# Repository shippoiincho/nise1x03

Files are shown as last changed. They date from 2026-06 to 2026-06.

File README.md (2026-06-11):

# 偽 1x03

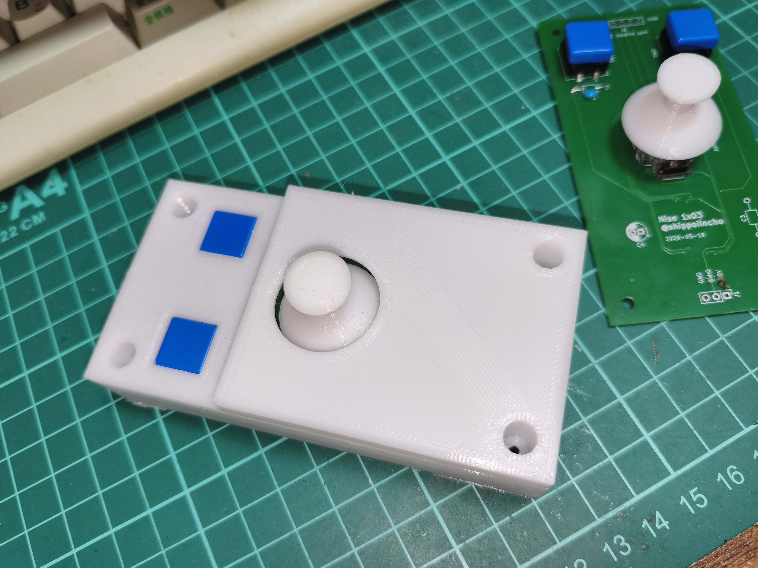
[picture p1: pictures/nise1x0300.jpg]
PCB


# これはなに

MZ-700/1500 用ジョイスティック MZ-1X03 のプロトコル互換のジョイスティックになります。
本体の専用コネクタに接続します。

# 回路とか

回路図は以下の通りになります。

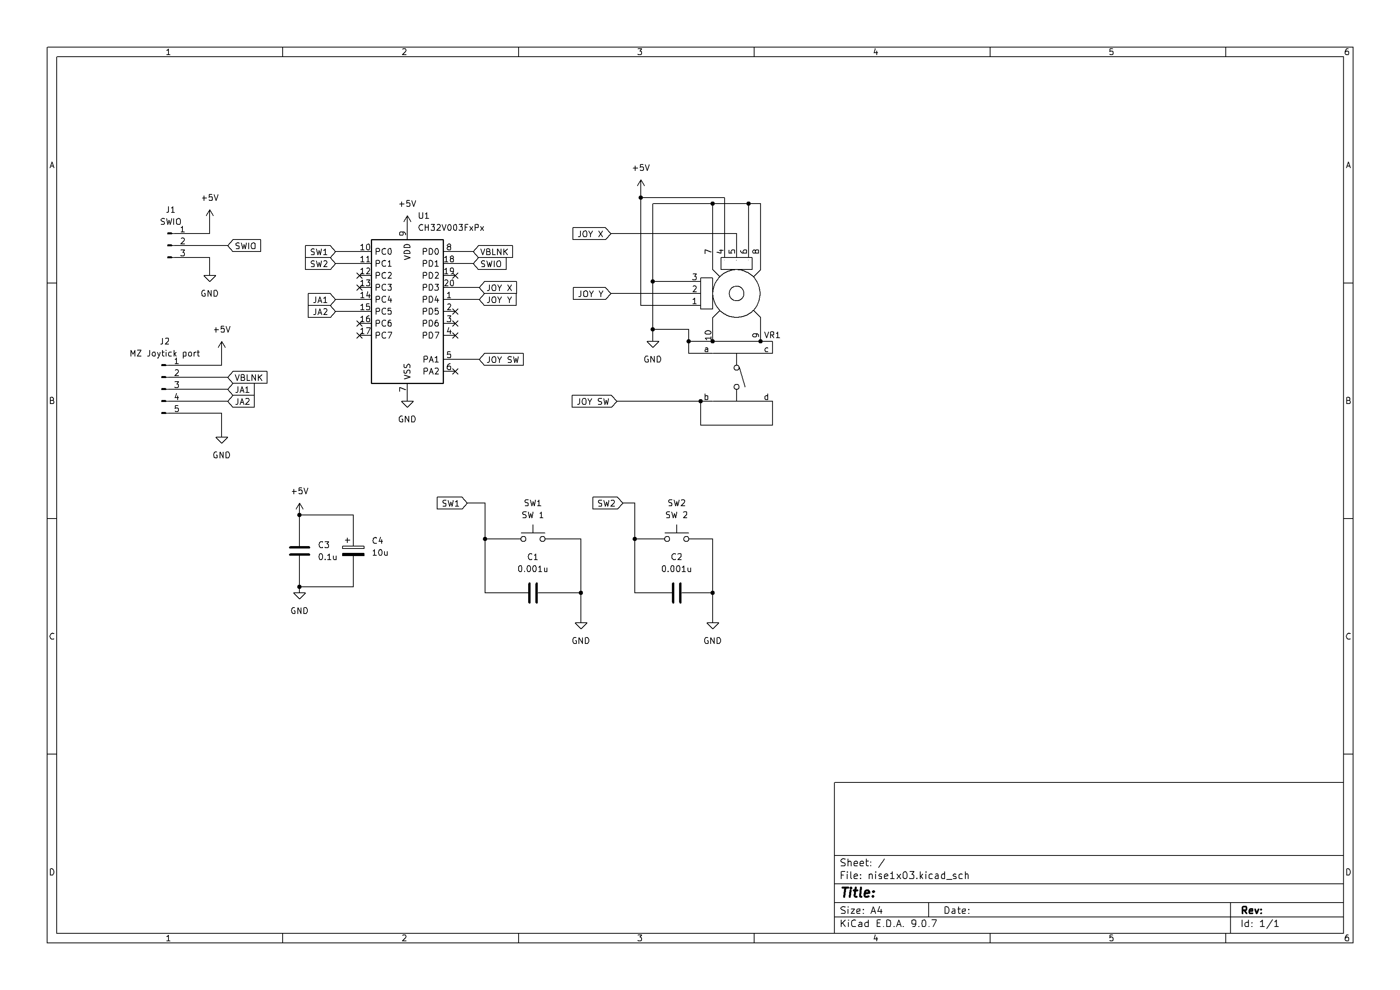
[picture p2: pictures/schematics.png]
schematics


HARDWARE の下にガーバデータと 3D プリンタ用筐体データがあります。

その他、必要なパーツは以下の通りです

- [CH32V003F4P6](https://akizukidenshi.com/catalog/g/g118061/)
- [ジョイスティックRKJXV122400R](https://akizukidenshi.com/catalog/g/g115951/)
- 12mm タクトスイッチ x2
- セラミックコンデンサ 1nF x 2
- セラミックコンデンサ 0.1uF x1
- 電解コンデンサ 10uF
- IL プラグ 5P
- IL コンタクト

本体のコネクタは向かって左が GND になっています。

# コードとか

MounRiverStudio (Ver.1) のプロジェクトになっています。
ビルドの上ファームウェアをダウンロードしてください。

書き込み用の端子は基板の下側にあります。

基板自体は CH32V00x シリーズで互換性がありますが、
ADC の仕様違いなどの関係で 003 以外で使用する場合には修正が必要です。

ジョイスティックの感度などは、以下のパラメータで調整できます。

```
#define SENSITIVE 13
#define TIMEFACTOR 850
```

BASIC の JOY 文などで、上(左)入力時に 0、下(右)入力時に 255 になるように調整してください。

# 制限事項

- 市販ソフトでの動作は未保障です
- ST-2 では感度２以上で動作することを確認をしています

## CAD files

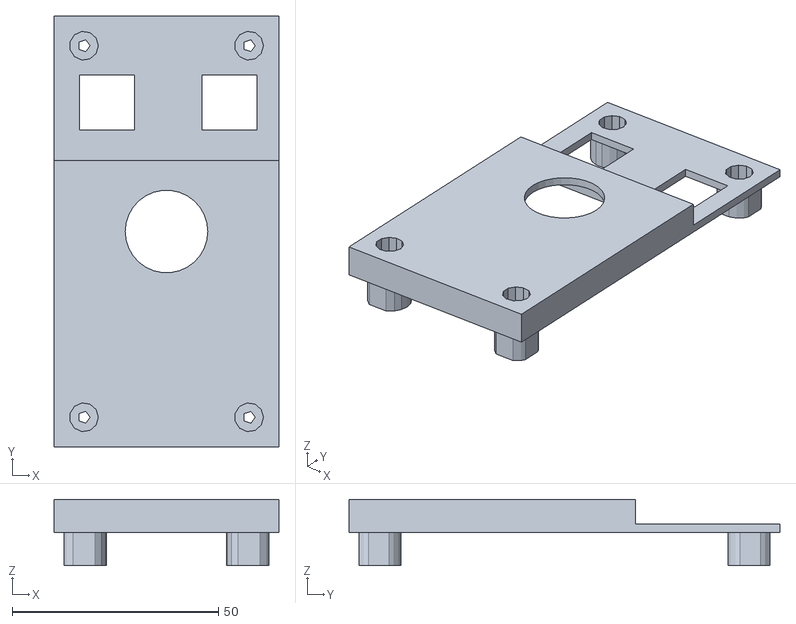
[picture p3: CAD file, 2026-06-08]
HARDWARE/MZ-1X03_top.stl
54.4 x 104.4 x 16.0

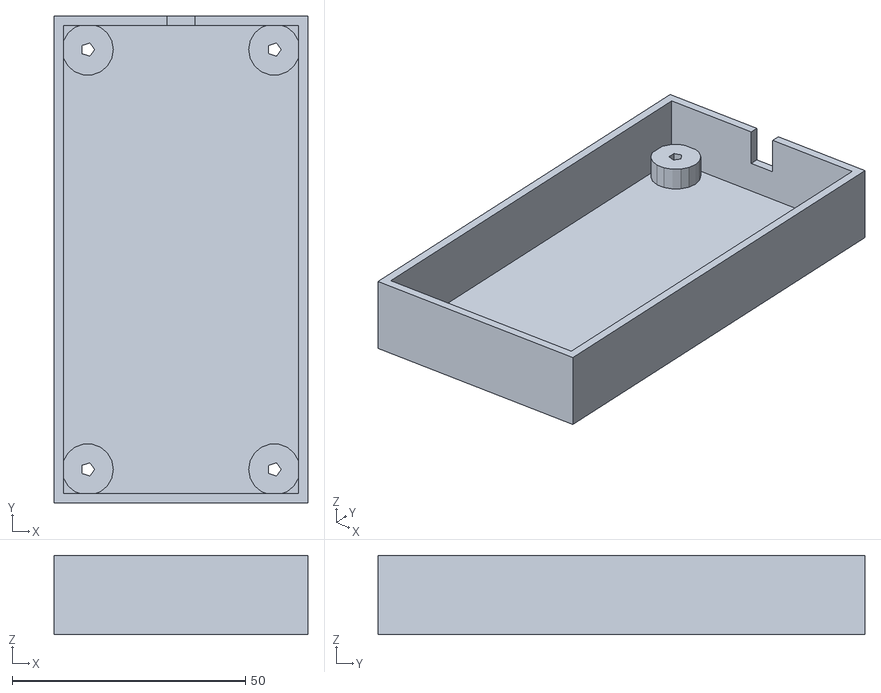
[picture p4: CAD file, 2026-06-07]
HARDWARE/MZ-1X03_bottom.stl
54.4 x 104.4 x 17.0

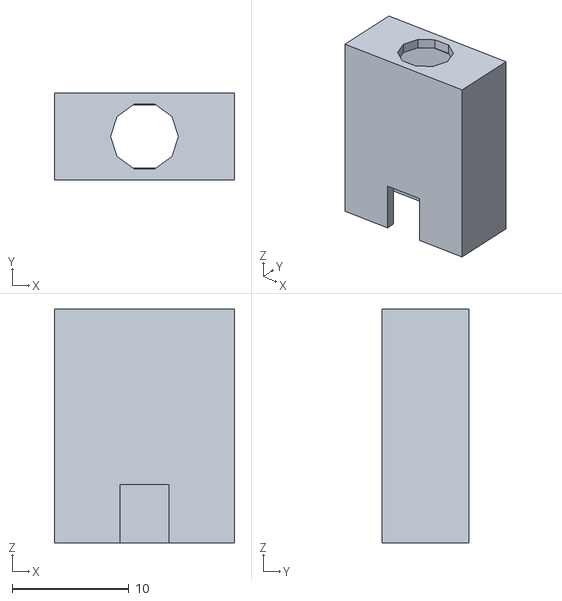
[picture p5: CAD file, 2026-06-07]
HARDWARE/MZ-1X03_conn.stl
15.4 x 7.40 x 20.0

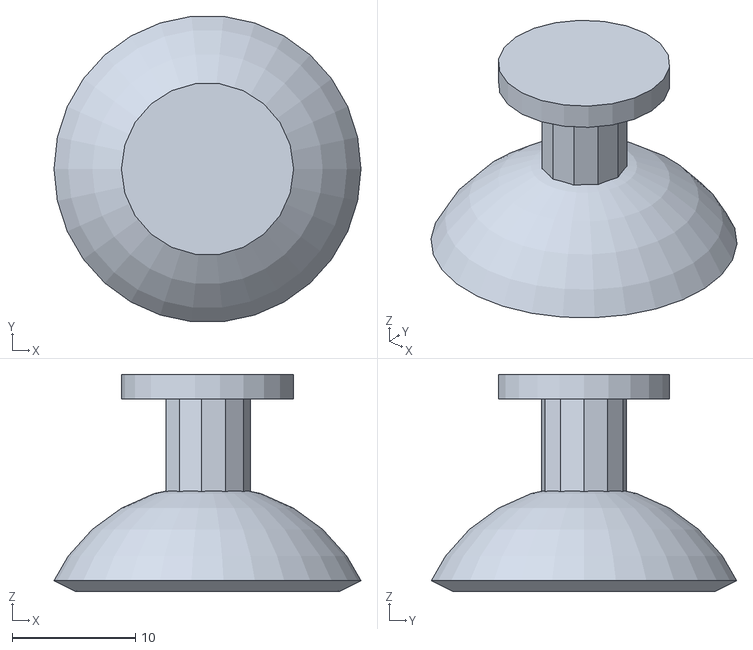
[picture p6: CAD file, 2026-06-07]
HARDWARE/MZ-1X03_cap.stl
25.0 x 24.8 x 17.7

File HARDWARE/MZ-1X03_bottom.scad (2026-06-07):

DEPTH=15;
SIZEX=25;
SIZEY=50;
HOLE=5;

MARGIN=0.2;
THICK=2.0;

DIFF=THICK/2;

// OUTER BOX

difference() {

translate([-SIZEX-MARGIN-THICK,-SIZEY-MARGIN-THICK,-DEPTH-THICK]) {    
cube([SIZEX*2+MARGIN*2+THICK*2,SIZEY*2+MARGIN*2+THICK*2,DEPTH+THICK]);
}

{
translate([-SIZEX-MARGIN,-SIZEY-MARGIN,-DEPTH]) {  
cube([SIZEX*2+MARGIN*2,SIZEY*2+MARGIN*2,DEPTH]);
}

// Mounting Hole

translate([-SIZEX+HOLE,-SIZEY+HOLE,-DEPTH-THICK]) {
cylinder(THICK,3.5,3.5);    
}

translate([-SIZEX+HOLE,SIZEY-HOLE,-DEPTH-THICK]) {
cylinder(THICK,3.5,3.5);    
}

translate([SIZEX-HOLE,-SIZEY+HOLE,-DEPTH-THICK]) {
cylinder(THICK,3.5,3.5);    
}

translate([SIZEX-HOLE,SIZEY-HOLE,-DEPTH-THICK]) {
cylinder(THICK,3.5,3.5);    
}

// Cable Guide

translate([-3,SIZEY,-8]) {
    cube([6,6,8]);
}

}

}

// Mounting Hole

difference() {
translate([-SIZEX+HOLE,-SIZEY+HOLE,-DEPTH]) {
cylinder(DEPTH-12,5.5,5.5);    
}
translate([-SIZEX+HOLE,-SIZEY+HOLE,-DEPTH]) {
cylinder(DEPTH-12,3.5,3.5);    
}
}

difference() {
translate([-SIZEX+HOLE,-SIZEY+HOLE,-12]) {
cylinder(2,5.5,5.5);    
}

translate([-SIZEX+HOLE,-SIZEY+HOLE,-12]) {
cylinder(2,1.5,1.5);    
}
}


difference() {
translate([-SIZEX+HOLE,SIZEY-HOLE,-DEPTH]) {
cylinder(DEPTH-12,5.5,5.5);    
}
translate([-SIZEX+HOLE,SIZEY-HOLE,-DEPTH]) {
cylinder(DEPTH-12,3.5,3.5);    
}
}

difference() {
translate([-SIZEX+HOLE,SIZEY-HOLE,-12]) {
cylinder(2,5.5,5.5);    
}

translate([-SIZEX+HOLE,SIZEY-HOLE,-12]) {
cylinder(2,1.5,1.5);    
}
}


difference() {
translate([SIZEX-HOLE,-SIZEY+HOLE,-DEPTH]) {
cylinder(DEPTH-12,5.5,5.5);    
}
translate([SIZEX-HOLE,-SIZEY+HOLE,-DEPTH]) {
cylinder(DEPTH-12,3.5,3.5);    
}
}

difference() {
translate([SIZEX-HOLE,-SIZEY+HOLE,-12]) {
cylinder(2,5.5,5.5);    
}

translate([SIZEX-HOLE,-SIZEY+HOLE,-12]) {
cylinder(2,1.5,1.5);    
}
}


difference() {
translate([SIZEX-HOLE,SIZEY-HOLE,-DEPTH]) {
cylinder(DEPTH-12,5.5,5.5);    
}
translate([SIZEX-HOLE,SIZEY-HOLE,-DEPTH]) {
cylinder(DEPTH-12,3.5,3.5);    
}
}

difference() {
translate([SIZEX-HOLE,SIZEY-HOLE,-12]) {
cylinder(2,5.5,5.5);    
}

translate([SIZEX-HOLE,SIZEY-HOLE,-12]) {
cylinder(2,1.5,1.5);    
}
}

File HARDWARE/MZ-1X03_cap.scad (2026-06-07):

MARGIN=0.2;

difference() {

intersection() {

difference() {
    
sphere(14);

sphere(12);

}

cylinder(15,0,30);

}

translate([-2-MARGIN,-1.5-MARGIN,10]) {
cube([4+MARGIN*2,3+MARGIN*2,4]);
}

}



difference() {

translate([0,0,11]) {
    cylinder(10,3.5,3.5);
}

translate([-2-MARGIN,-1.5-MARGIN,11]) {
cube([4+MARGIN*2,3+MARGIN*2,5]);
}


}

translate([0,0,21]) {
    cylinder(2,7,7);
}

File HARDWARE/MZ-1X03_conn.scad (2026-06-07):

difference() {

translate([-7.7,-3.7,0]) {    
cube([15.4,7.4,20]);
}

{
translate([-6.6,-2.7,0]) {  
cube([13.4,5.4,19]);
}

translate([-2.1,-3.7,-0]) {       
cube([4.2,2.2,5]);
    
}

translate([0,0,19]) {

cylinder(5,2.9,2.9);    
    
}

}

}

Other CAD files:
HARDWARE/MZ-1X03_top.scad

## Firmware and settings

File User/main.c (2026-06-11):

// Nise 1x03
// MZ-1X03 Emulator

// Pin connections
// PC0: SW1
// PC1: SW2
// PC4: JA1
// PC5: JA2
// PD0: VBLNK
// PD3: JOY X
// PD4: JOY Y

#include "debug.h"

#define SENSITIVE 13
#define TIMEFACTOR 850


// Initialize

void initgpio(void) {

    RCC_APB2PeriphClockCmd(RCC_APB2Periph_GPIOD | RCC_APB2Periph_GPIOC, ENABLE);


    GPIO_InitTypeDef  GPIO_InitStructure = {0};

    // PC0 & 1 for input with pull up

    GPIO_InitStructure.GPIO_Pin = GPIO_Pin_0 | GPIO_Pin_1;
    GPIO_InitStructure.GPIO_Speed = GPIO_Speed_50MHz;
    GPIO_InitStructure.GPIO_Mode = GPIO_Mode_IPU;
    GPIO_Init(GPIOC, &GPIO_InitStructure);

    // PC4 & 5 for output

    GPIO_InitStructure.GPIO_Pin = GPIO_Pin_4 | GPIO_Pin_5;
    GPIO_InitStructure.GPIO_Speed = GPIO_Speed_50MHz;
    GPIO_InitStructure.GPIO_Mode = GPIO_Mode_Out_PP;
    GPIO_Init(GPIOC, &GPIO_InitStructure);

    // PD0 for input

    GPIO_InitStructure.GPIO_Pin = GPIO_Pin_0 ;
    GPIO_InitStructure.GPIO_Speed = GPIO_Speed_50MHz;
    GPIO_InitStructure.GPIO_Mode = GPIO_Mode_IPU;
    GPIO_Init(GPIOD, &GPIO_InitStructure);

    // PD3 & 4 for ADC ch 4/5

    GPIO_InitStructure.GPIO_Pin = GPIO_Pin_3 | GPIO_Pin_4;
    GPIO_InitStructure.GPIO_Speed = GPIO_Speed_50MHz;
    GPIO_InitStructure.GPIO_Mode = GPIO_Mode_AIN;
    GPIO_Init(GPIOD, &GPIO_InitStructure);

}

void initadc(void) {

    ADC_InitTypeDef  ADC_InitStructure = {0};

    RCC_APB2PeriphClockCmd(RCC_APB2Periph_ADC1, ENABLE);
    RCC_ADCCLKConfig(RCC_PCLK2_Div8);

    ADC_DeInit(ADC1);
    ADC_InitStructure.ADC_Mode = ADC_Mode_Independent;
    ADC_InitStructure.ADC_ScanConvMode = DISABLE;
    ADC_InitStructure.ADC_ContinuousConvMode = DISABLE;
    ADC_InitStructure.ADC_ExternalTrigConv = ADC_ExternalTrigConv_None;
    ADC_InitStructure.ADC_DataAlign = ADC_DataAlign_Right;
    ADC_InitStructure.ADC_NbrOfChannel = 1;
    ADC_Init(ADC1, &ADC_InitStructure);

    ADC_Calibration_Vol(ADC1, ADC_CALVOL_50PERCENT);
    ADC_Cmd(ADC1, ENABLE);

    ADC_ResetCalibration(ADC1);
    while(ADC_GetResetCalibrationStatus(ADC1));
    ADC_StartCalibration(ADC1);
    while(ADC_GetCalibrationStatus(ADC1));


}

uint16_t getadc(uint8_t ch)
{
    uint16_t val;

    ADC_RegularChannelConfig(ADC1, ch, 1, ADC_SampleTime_241Cycles);
    ADC_SoftwareStartConvCmd(ADC1, ENABLE);

    while(!ADC_GetFlagStatus(ADC1, ADC_FLAG_EOC));
    val = ADC_GetConversionValue(ADC1);

    return val;
}

// ADC value to Timer conversion
// ADC   Max value = 1023 (10bit)
// Timer Max value = 255 * 7.84usec

static inline uint32_t calc_timer(uint16_t adcval) {

    int32_t temp;

    // ADC value expansion ( x 1,25 )

    temp = adcval - 512;

    temp = (temp*SENSITIVE)/10;

    // Cap

    if(temp<-512) temp=-512;
    if(temp>511) temp=511;

    temp += 512;

    // Joystick 1 count = 7.84 usec

    temp = (temp * TIMEFACTOR ) / 400;

    return (uint32_t)temp;

}


int main(void)
{
    uint16_t adc_x,adc_y,sws;
    uint32_t time_x,time_y;

    NVIC_PriorityGroupConfig(NVIC_PriorityGroup_1);
    SystemCoreClockUpdate();
    Delay_Init();

 // Initialize GPIOs

    initgpio();
    initadc();

    // Joystick initial value

    adc_x=getadc(ADC_Channel_4);
    adc_y=getadc(ADC_Channel_7);

//    time_x= adc_x * 78 / 40 ;
//    time_y= adc_y * 78 / 40 ;

    time_x= calc_timer(adc_x);
    time_y= calc_timer(adc_y);

    while(1)
    {

        // WAIT  VBLNK to Low

        while(GPIO_ReadInputDataBit(GPIOD, GPIO_Pin_0)==Bit_SET) ;

        GPIO_WriteBit(GPIOC, GPIO_Pin_4, Bit_RESET);
        GPIO_WriteBit(GPIOC, GPIO_Pin_5, Bit_RESET);

        // WAIT 280cycles = 78usec
        Delay_Us(78);

//        GPIO_WriteBit(GPIOC, GPIO_Pin_4, Bit_SET);
//        GPIO_WriteBit(GPIOC, GPIO_Pin_5, Bit_SET);

        // WAIT

        if(adc_y>=adc_x) {

            Delay_Us(time_x);
            GPIO_WriteBit(GPIOC, GPIO_Pin_4, Bit_SET);

            Delay_Us(time_y-time_x);
            GPIO_WriteBit(GPIOC, GPIO_Pin_5, Bit_SET);

        } else {

            Delay_Us(time_y);
            GPIO_WriteBit(GPIOC, GPIO_Pin_5, Bit_SET);

            Delay_Us(time_x-time_y);
            GPIO_WriteBit(GPIOC, GPIO_Pin_4, Bit_SET);

        }

        // WAIT  VBLNK to High

        while(GPIO_ReadInputDataBit(GPIOD, GPIO_Pin_0)==Bit_RESET) ;

        // send BUTTON Status

        sws=GPIO_ReadInputData(GPIOC);

        if(sws&1) {
            GPIO_WriteBit(GPIOC, GPIO_Pin_4, Bit_SET);
        } else {
            GPIO_WriteBit(GPIOC, GPIO_Pin_4, Bit_RESET);
        }

        if(sws&2) {
            GPIO_WriteBit(GPIOC, GPIO_Pin_5, Bit_SET);
        } else {
            GPIO_WriteBit(GPIOC, GPIO_Pin_5, Bit_RESET);
        }



        adc_x=getadc(ADC_Channel_4);
        adc_y=getadc(ADC_Channel_7);

        time_x= calc_timer(adc_x);
        time_y= calc_timer(adc_y);

    }
}

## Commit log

2026-06-07 fix README
    [MZ-1X03_bottom.scad, MZ-1X03_bottom.stl, MZ-1X03_cap.scad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]
2026-06-08 change button hole size
    [MZ-1X03_top.scad, MZ-1X03_top.stl]
